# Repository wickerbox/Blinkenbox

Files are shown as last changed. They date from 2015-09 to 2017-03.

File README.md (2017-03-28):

Blinkenbox IoT Device 
---------------------

LEDs driven by an ESP8266 module with battery charge circuit. 

I used an Adafruit Huzzah (with an ESP8266-based ESP12E) to log onto a local hotspot at Portland Mini Maker Faire and create a webpage where you could change the color of the RGB LED by clicking on the buttons. You could select one of six preset colors directly, or you could adjust the red, green, or blue components separately.

It didn’t hold up as well as I would have liked in broad daylight, but the diffused box (made by Stefan) was really nice.







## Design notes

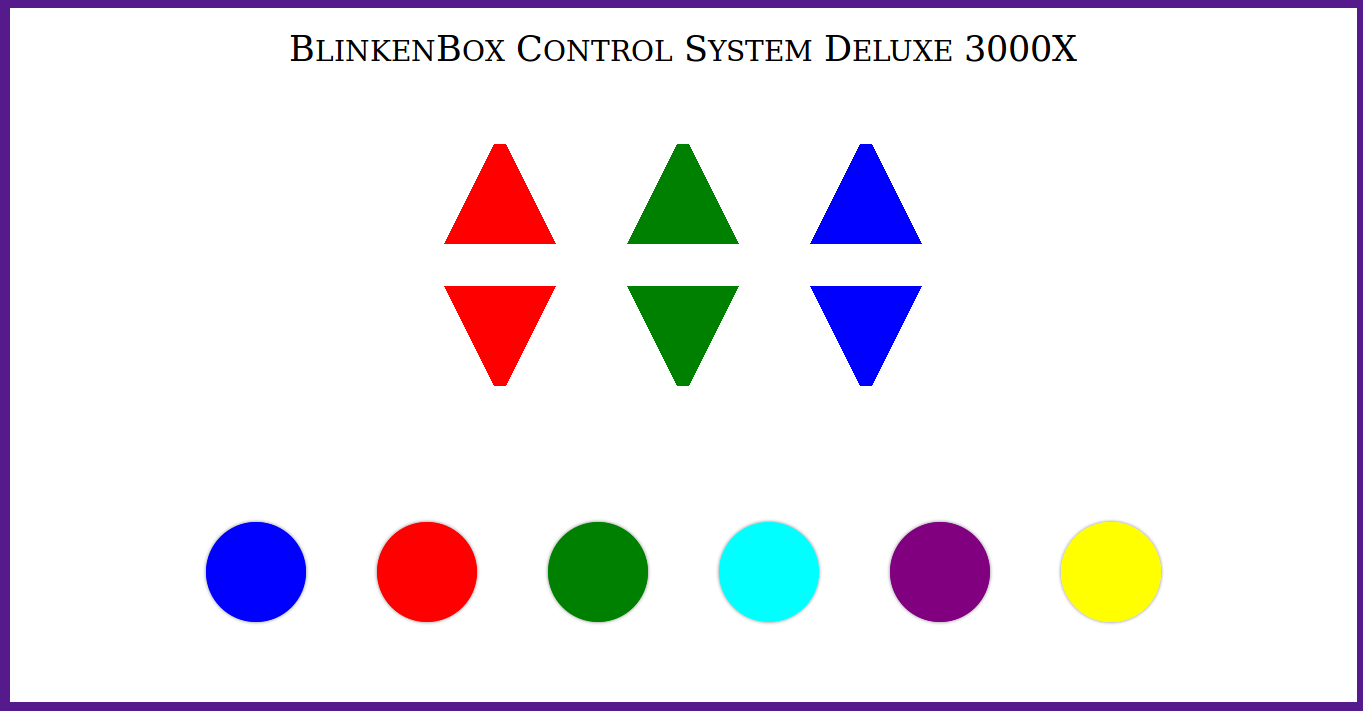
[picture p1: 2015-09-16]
webpage/blinken-v1-webview.png

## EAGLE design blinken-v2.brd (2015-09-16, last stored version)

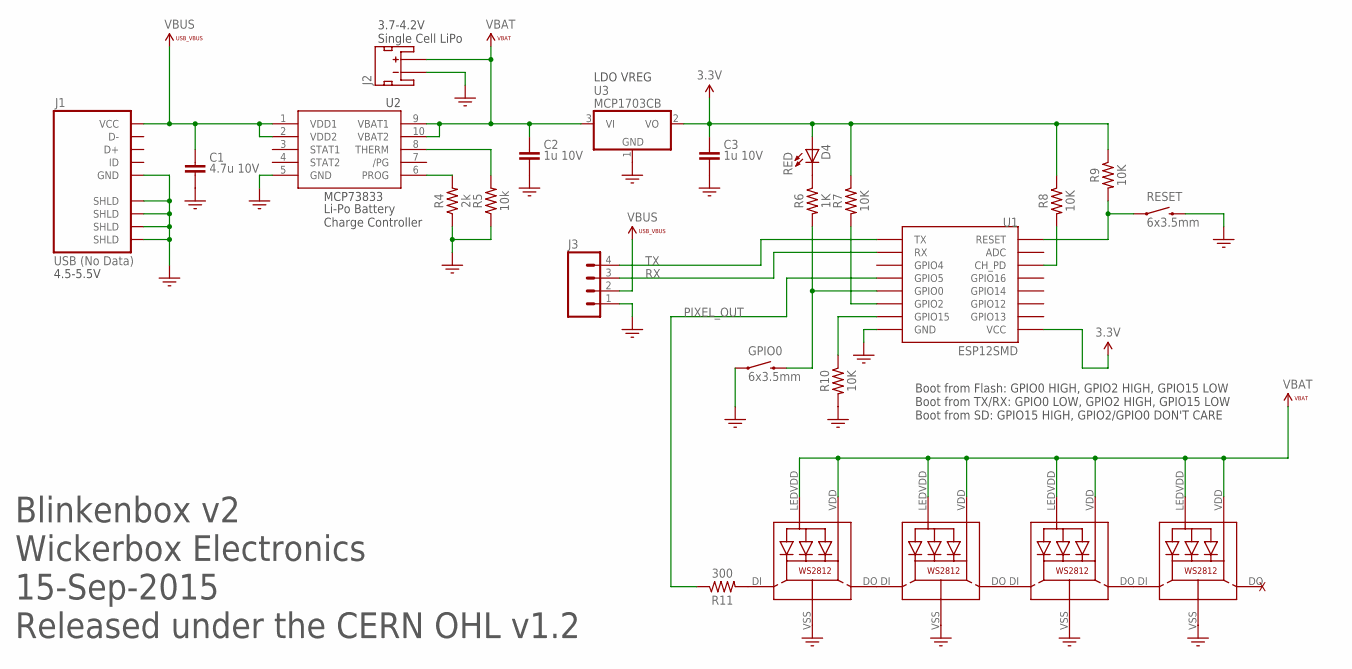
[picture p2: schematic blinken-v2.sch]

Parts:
C1: 4.7u 10V; RLC-0805
C2, C3: 1u 10V; RLC-0603
D4: RED; LED0603
GPIO0: 6x3.5mm; TACTILE-SWITCH-1101NE
J1: USB (No Data); ZX62D-B-5P8
J2: JST_2MM_MALE; JST-2-SMD
J3: M041X04_NO_SILK; 1X04_NO_SILK
LED1, LED2, LED3, LED4: WS2812
R4: 2k; RLC-0402
R5: 10k; RLC-0402
R6: 1K; RLC-0402
R7, R8, R9, R10: 10K; RLC-0402
R11: 300; RLC-0402
RESET: 6x3.5mm; TACTILE-SWITCH-1101NE
U1: ESP12SMD; ESP12_SMD
U2: MCP73833-UN; MSOP10
U3: MCP1703CB; SOT23

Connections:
3.3V: C3.2 (1), D4.A, R7.1, R8.1, R9.1, U1.VCC, U3.2 (VO)
!RESET: R9.2, RESET.1, U1.RESET
CH_PD: R8.2, U1.CH_PD
GND: C1.2, C2.1 (2), C3.1 (2), GPIO0.1, J1.P5 (GND), J1.P$1 (SHLD), J1.P$2 (SHLD), J1.P$3 (SHLD), J1.P$4 (SHLD), J2.1 (-), J3.1, LED1.VSS (GND), LED2.VSS (GND), LED3.VSS (GND), LED4.VSS (GND), R4.1, R5.1, R10.2, RESET.2, U1.GND, U2.5 (GND), U3.1 (GND)
GPIO0: GPIO0.2, R6.2, U1.GPIO0
GPIO2: R7.2, U1.GPIO2
GPIO15: R10.1, U1.GPIO15
unnamed: LED1.DO, LED2.DI
unnamed: D4.C, R6.1
unnamed: LED2.DO, LED3.DI
unnamed: LED3.DO, LED4.DI
unnamed: LED1.DI, R11.2
PIXEL_OUT: R11.1, U1.GPIO5
PROG: R4.2, U2.6 (PROG)
RX: J3.3, U1.RX
THERM: R5.2, U2.8 (THERM)
TX: J3.4, U1.TX
VBROUTE: C2.2 (1), J2.2 (+), LED1.LEDVDD, LED1.VDD, LED2.LEDVDD, LED2.VDD, LED3.LEDVDD, LED3.VDD, LED4.LEDVDD, LED4.VDD, U2.9 (VBAT1), U2.10 (VBAT2), U3.3 (VI)
VBUS: C1.1, J1.P1 (VCC), J3.2, U2.1 (VDD1), U2.2 (VDD2)

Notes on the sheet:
LDO VREG
4.5-5.5V
Li-Po Battery Charge Controller
3.7-4.2V Single Cell LiPo
Blinkenbox v2 Wickerbox Electronics 15-Sep-2015 Released under the CERN OHL v1.2
Boot from Flash: GPIO0 HIGH, GPIO2 HIGH, GPIO15 LOW Boot from TX/RX: GPIO0 LOW, GPIO2 HIGH, GPIO15 LOW Boot from SD: GPIO15 HIGH, GPIO2/GPIO0 DON'T CARE

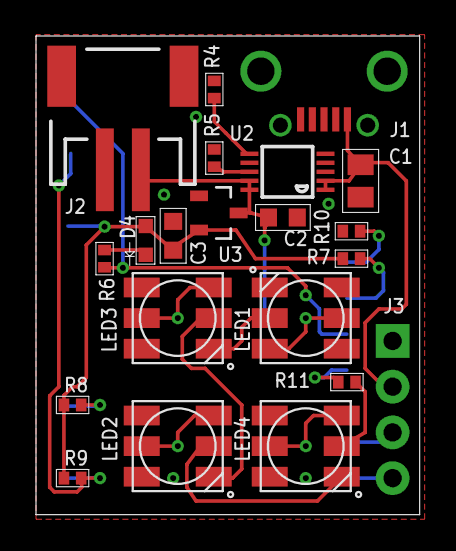
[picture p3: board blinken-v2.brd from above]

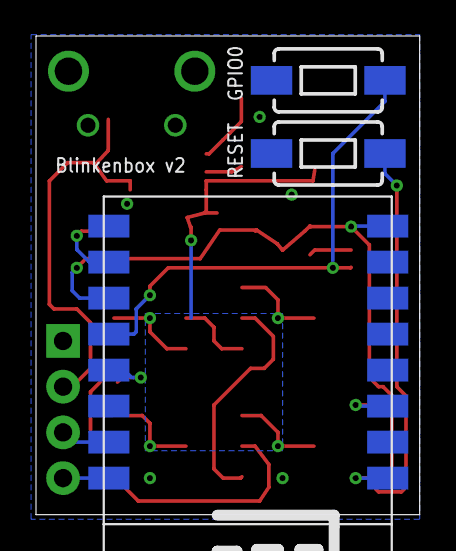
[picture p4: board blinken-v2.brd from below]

Board: 2 copper layers, 21.3 x 26.6 mm, 24 parts (3 on the bottom side), 19 nets.

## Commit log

2015-09-16 Ordering this board. BOM added to README.
    [blinken-v2.brd, blinken-v2.sch]
2016-01-31 All the things.
    [blinken-v2.drills.xln]
2017-03-28 Reverted to v1 and cleaned README.
    [blinken-v2.brd, blinken-v2.sch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]

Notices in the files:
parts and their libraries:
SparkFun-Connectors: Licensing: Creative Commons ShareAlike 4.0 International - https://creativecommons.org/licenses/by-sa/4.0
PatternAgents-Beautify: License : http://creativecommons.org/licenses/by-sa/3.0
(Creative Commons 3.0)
